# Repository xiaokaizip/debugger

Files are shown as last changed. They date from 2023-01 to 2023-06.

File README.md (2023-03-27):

#### 调试器电路

##### 主控（stm32f401rct6）

##### 屏幕（tft屏）

##### 闪存（W25Q32JVSSIQ）

##### 触摸功能（XPT2946）

##### 按键

#### 代码

##### tft屏驱动

- tft屏幕与主控使用spi通讯，然后为了提高屏幕的刷新率，我使用了DMA进行数据的传输。
- tft屏幕的配置更多还是使用网上的库，方便直接。
- 学会更好的使用DMA

##### 触摸功能

- 触摸的功能相对于tft屏幕的驱动来说，是比较好写，但是要完善也还不是很容易，它的功能还需再来研究。

==这两部分可以借鉴老朱的代码（手动狗头），养成写注释的习惯，等到功能写出来再来整理到readme中==

# Debegger

## 代码的设计

### tft屏幕显示

- spi的配置，如下图：（然后再开启个DMA就可以了）

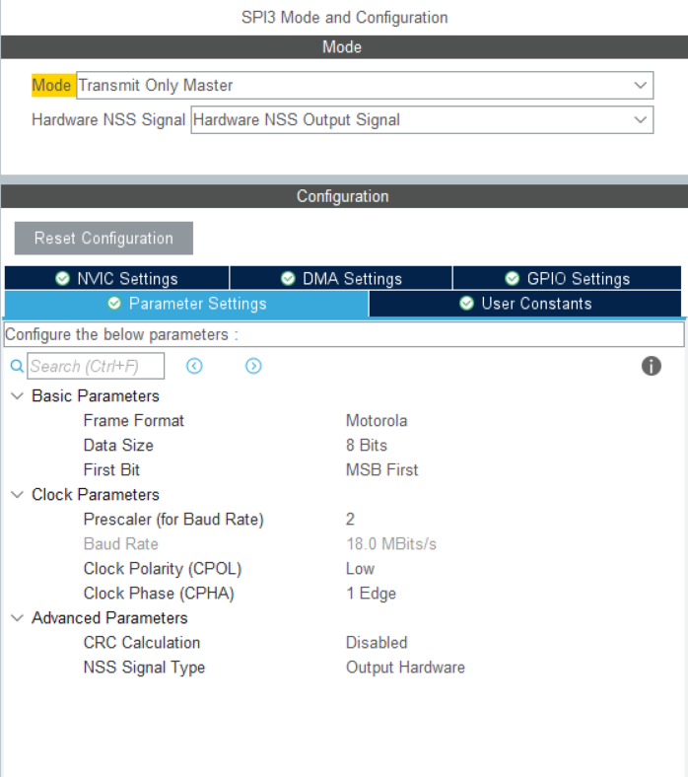
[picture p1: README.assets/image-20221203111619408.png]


- 屏幕的初始化还是使用普通的方法对其进行初始化（那些初始化的指令还没去了解）。

- 首先是屏幕的设计，目前的想法是，先将一整个屏幕的数据处理完，再使用DMA传输一次性完成传输。（已完成）

- 先将要处理的像素点存储到数组中

~~~c
volatile unsigned char lcd_buffer[128 * 160 * 2] = {0};

~~~

然后直接使用DMA将数据传输到ftf屏中

~~~c
    HAL_SPI_Transmit_DMA(&hspi3, (uint8_t *) lcd_buffer, 128 * 160 * 2);
~~~

- 然后就是对数组的处理了，每一个数组对应tft屏中的一个像素点，所以在处理时，只需将对应的像素点输入对应的颜色指令即可。
  - 在此代码中对应的字符大小为12*6，即宽为6像素，高为12像素。
  - 处理字符时，先从行开始处理的，依次向下处理。
  - 至于其他的方框，就是直接抄袭老朱的代码。（还需待我看懂）

### 串口数据的处理

##### 配置

- 首先是串口的接口，在本调试器中，使用的串口是USART1和UART4

  - usart1：typeC接口，具有usb2ttl芯片

    PA10->RX

    PA9->TX

  - uart4：使用的是gh1.25的接口。

    PC10->TX

    PC11->RX

- 发送数据的时候，还是用了轮询模式。接收数据的时候，使用的是中断模式。

##### 数据类型转换

- 串口传输的是8位的数，所以如果要传输更长的数据类型，需要转换一下数据的类型。在本例程中要传输的是float的数据，所以float和unsigned short 两种类型的数据相互转换。

- 将float转换为unsigned short

  ~~~c
  unsigned short FloatToInt16(float data0)
  ~~~

- 将unsigned short转换为float

  ~~~c
  float Int16ToFloat(unsigned short data0)
  
  ~~~

##### 传输格式

- 目前暂定传输和接收4个float类型数据（这四个数据分别为data1、data2、data3、data4）。使用长度为11的数据。

| 0 | 1 | 2 | 3 | 4 | 5 | 6 | 7 | 8 | 9 | 10 |
| ---- | ---- | ---- | ---- | ---- | ---- | ---- | ---- | ---- | --- | ---- |
| 0xff | 高位 | 低位 | 高位 | 低位 | 高位 | 低位 | 高位 | 低位 | 校准位 | 0xff |

- 第零位为起始位，指定为0xff，低十位为结束位，指定为0xff。
- 第1位是data1的高8位，第2位是data1低8位。其他的以此类推。
- 第9位是校准位，其实起这个名字可能不太合适，这一位的作用就是用来表示接收了多少个有效数据（非零数据）

## 图形界面的设计

### 现阶段流程图

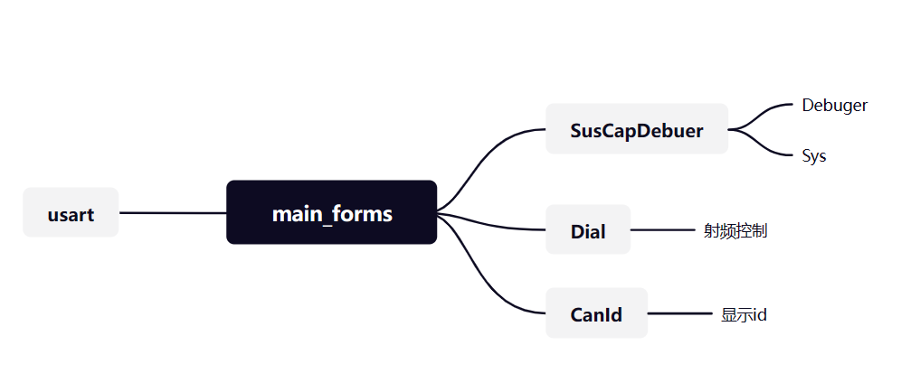
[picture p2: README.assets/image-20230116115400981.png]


- 在每一个界面中都有一个TurnBuck选项（除了main_forms界面），按下此界面就会回到上一个界面。这个回调的方法不知是要不要使用链表（有待思考）。

- 图形界面只是使用了按键（Button）以及标签（label）来设计的简易界面。Key1用来移动光标，Key2用来确定进入相依的界面，并使用回调函数还进行初始化，配合链表可能会有更好的效果。

### 设计思路

- key1为选择键，当key1按下时key_Select_flag++；同时相应的button将会高亮表示被选择到。
- 当按下key2时，为确定按键。此时key_Verify_flag=1。此时将会根据key_Select_flag的值调用 相应 的回调函数 进入相应的界面。然后key_Verify_flag被重新置零。
- 此流程是相对较简单的。后面的想法是使用链表来实现界面的切换 。

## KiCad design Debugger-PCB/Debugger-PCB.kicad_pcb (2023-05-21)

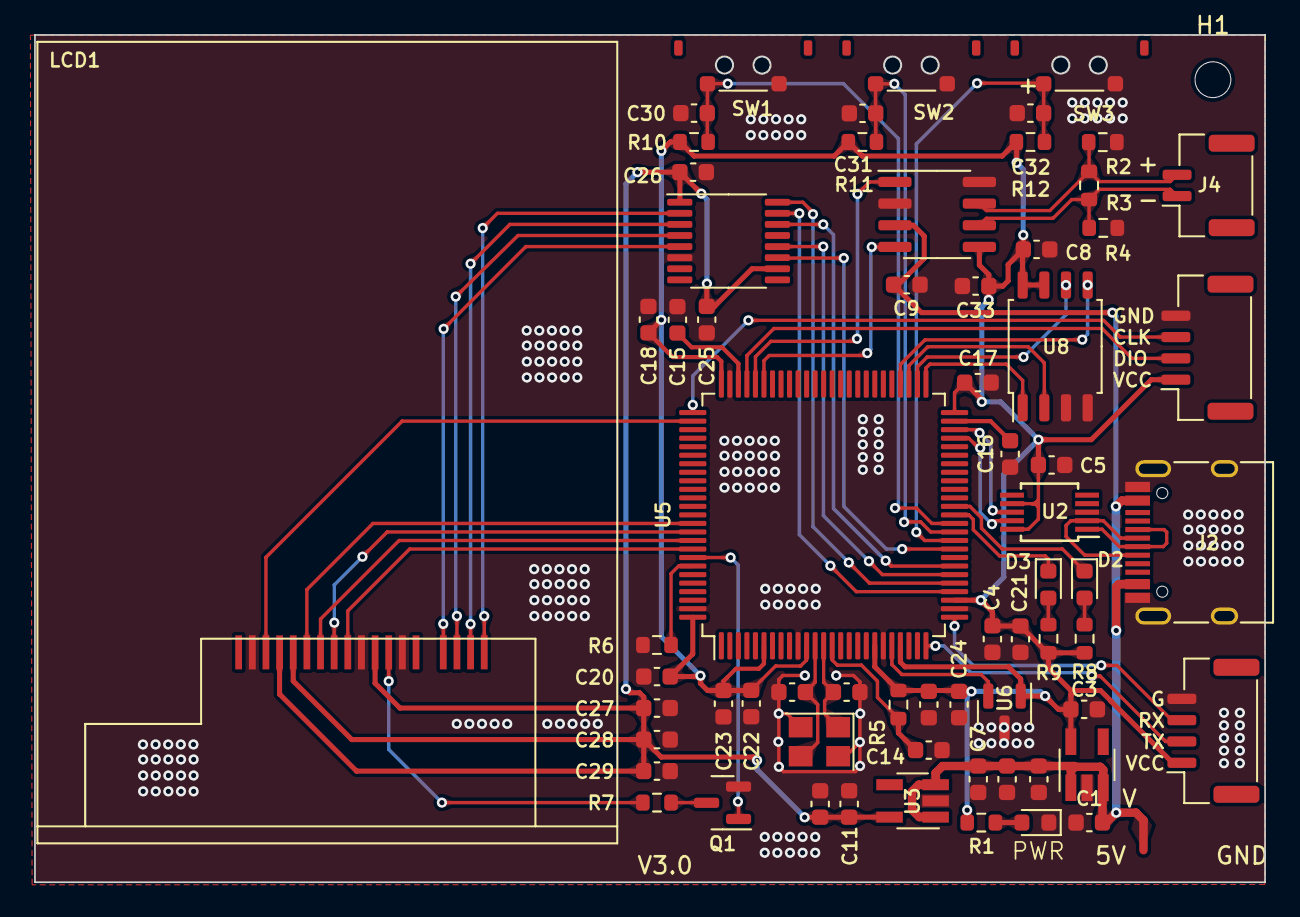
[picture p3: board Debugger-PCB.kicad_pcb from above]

Board: 2 copper layers, 72.1 x 49.7 mm, 67 parts (0 on the bottom side), 52 nets.

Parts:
C1, C4, C6, C11: 10u; C_0603_1608Metric
C2, C3, C5, C7, C8, C9, C10, C14, C17, C18, C19, C20, C21, C22, C23, C24, C25, C26, C27, C28, C29, C30, C31, C32, C33: 100n; C_0603_1608Metric
C12, C13: 12p; C_0603_1608Metric
C15, C16: 2.2u; C_0603_1608Metric
D1, D2, D3: LED; LED_0603_1608Metric
H1: mountinghole; MountingHole_2.1mm
J1, J3: Conn_01x04; JST_GH_SM04B-GHS-TB_1x04-1MP_P1.25mm_Horizontal
J2: USB_C_Receptacle_USB2.0; USB_C_Receptacle_HRO_TYPE-C-31-M-12
J4: Conn_01x02; JST_GH_SM02B-GHS-TB_1x02-1MP_P1.25mm_Horizontal
LCD1: 1.8inch-TFT-LCD; TFT-LCD1.8inch
Q1: S8050; SOT-23
R1, R8, R9, R10, R11, R12: 1k; R_0603_1608Metric
R2, R4, R5: 10k; R_0603_1608Metric
R3: 120; R_0603_1608Metric
R6: 10K; R_0603_1608Metric
R7: R; R_0603_1608Metric
SW1, SW2, SW3: SW_Push; button
U1, U3: HX9193; SOT-23-5_HandSoldering
U2: CH340E; MSOP-10_3x3mm_P0.5mm
U4: TJA1051T-3; SOIC-8_3.9x4.9mm_P1.27mm
U5: STM32F407VETx; LQFP-100_14x14mm_P0.5mm
U6: REF3030; SOT-23
U7: XPT2046TS; TSSOP-16_4.4x5mm_P0.65mm
U8: W25Q32JVSS; SOIC-8_5.23x5.23mm_P1.27mm
Y1: 12M; Crystal_SMD_3225-4Pin_3.2x2.5mm

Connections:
+5V: C1.1, C2.1, C6.1, C7.1, C9.1, J2.A4 (VBUS), J2.A9 (VBUS), J2.B4 (VBUS), J2.B9 (VBUS), U1.1 (VIN), U1.3 (EN), U3.1 (VIN), U3.3 (EN), U4.3 (VCC)
/Flash/SPI2_CS: U5.51 (PB12), U8.1 (~CS)
/Flash/SPI2_MISO: U5.53 (PB14), U8.2 (DO(IO1))
/Flash/SPI2_MOSI: U5.54 (PB15), U8.5 (DI(IO0))
/Flash/SPI2_SCK: U5.52 (PB13), U8.6 (CLK)
/Key&LED/KEY1: C30.1, R10.2, SW1.2, U5.37 (PB2)
/Key&LED/KEY2: C31.1, R11.2, SW2.2, U5.36 (PB1)
/Key&LED/KEY3: C32.1, R12.2, SW3.2, U5.35 (PB0)
/Key&LED/LED1: D2.1 (K), U5.39 (PE8)
/Key&LED/LED2: D3.1 (K), U5.38 (PE7)
/MCU/CAN_RX: U4.4 (RXD), U5.70 (PA11)
/MCU/CAN_TX: U4.1 (TXD), U5.71 (PA12)
/MCU/LCD_A0: LCD1.7 (A0), U5.90 (PB4)
/MCU/LCD_CLK: LCD1.9 (CLK), U5.89 (PB3)
/MCU/LCD_CS: LCD1.12 (CS), U5.77 (PA15)
/MCU/LCD_LED: Q1.1 (B), U5.93 (PB7)
/MCU/LCD_MOSI: LCD1.8 (DI), U5.91 (PB5)
/MCU/LCD_RST: LCD1.6 (~RESET), U5.92 (PB6)
/MCU/MCU_RXD: U2.8 (TXD), U5.48 (PB11)
/MCU/MCU_TXD: U2.9 (RXD), U5.47 (PB10)
/MCU/OSC_IN: C13.1, U5.12 (PH0), Y1.3
/MCU/OSC_OUT: C12.1, U5.13 (PH1), Y1.1
/MCU/RXD: J1.3, U5.26 (PA3)
/MCU/SWCLK: J3.3, U5.76 (PA14)
/MCU/SWDIO: J3.2, U5.72 (PA13)
/MCU/TOUCH_CLK: U5.30 (PA5), U7.16 (DCLK)
/MCU/TOUCH_CS: U5.29 (PA4), U7.15 (~CS)
/MCU/TOUCH_INT: U5.34 (PC5), U7.11 (~PENIRQ)
/MCU/TOUCH_MISO: U5.31 (PA6), U7.12 (DOUT)
/MCU/TOUCH_MOSI: U5.32 (PA7), U7.14 (DIN)
/MCU/TXD: J1.2, U5.25 (PA2)
/MCU/VREF: U5.21 (VREF+), U6.2 (OUT)
/Power&Port/CAN+: J4.2, R2.2, R3.1, U4.7 (CANH)
/Power&Port/CAN-: J4.1, R3.2, R4.1, U4.6 (CANL)
/Power&Port/DN: J2.A7 (D-), J2.B7 (D-), U2.2 (UD-)
/Power&Port/DP: J2.A6 (D+), J2.B6 (D+), U2.1 (UD+)
/TFT/LED-: LCD1.3 (LED-), R7.1
/TFT/T_XM: LCD1.16 (X-), U7.4 (XN)
/TFT/T_XP: LCD1.18 (X+), U7.2 (XP)
/TFT/T_YM: LCD1.15 (Y-), U7.5 (YN)
/TFT/T_YP: LCD1.17 (Y+), U7.3 (YP)
GND: C1.2, C2.2, C3.2, C4.2, C5.2, C6.2, C7.2, C8.2, C9.2, C10.2, C11.2, C12.2, C13.2, C14.1, C15.1, C16.1, C17.2, C18.2, C19.2, C20.2, C21.2, C22.2, C23.2, C24.2, C25.2, C26.2, C27.2, C28.2, C29.2, C30.2, C31.2, C32.2, C33.2, D1.1 (K), J1.4, J2.A1 (GND), J2.A12 (GND), J2.B1 (GND), J2.B12 (GND), J2.S1 (SHIELD), J3.4, LCD1.2 (GND), LCD1.5 (GND), LCD1.13 (GND), Q1.2 (E), R2.1, R4.2, R6.1, SW1.1, SW2.1, SW3.1, U1.2 (GND), U2.3 (GND), U3.2 (GND), U4.2 (GND), U4.8 (S), U5.10 (VSS), U5.20 (VSSA), U5.27 (VSS), U5.74 (VSS), U5.99 (VSS), U6.3 (GND), U7.6 (GND), U8.3 (IO2), U8.4 (GND), Y1.2, Y1.4
LCD_3V3: C10.1, C11.1, C25.1, C26.1, C27.1, C28.1, C29.1, LCD1.4 (LED+), LCD1.10 (VCC), LCD1.11 (IOVCC), U3.5 (VOUT), U7.1 (VCC), U7.10 (IOVDD)
unnamed: D1.2 (A), R1.2
unnamed: D2.2 (A), R8.2
unnamed: D3.2 (A), R9.2
unnamed: Q1.3 (C), R7.2
unnamed: R6.2, U5.94 (BOOT0)
unnamed: C14.2, R5.2, U5.14 (NRST)
unnamed: C16.2, U5.49 (VCAP_1)
unnamed: C15.2, U5.73 (VCAP_2)
VCC: C3.1, C4.1, C5.1, C8.1, C17.1, C18.1, C19.1, C20.1, C21.1, C22.1, C23.1, C24.1, C33.1, J1.1, J3.1, R1.1, R5.1, R8.1, R9.1, R10.1, R11.1, R12.1, U1.5 (VOUT), U2.7 (VCC), U2.10 (V3), U4.5 (VIO), U5.6 (VBAT), U5.11 (VDD), U5.19 (VDD), U5.22 (VDDA), U5.28 (VDD), U5.50 (VDD), U5.75 (VDD), U5.100 (VDD), U6.1 (IN), U8.7 (IO3), U8.8 (VCC)

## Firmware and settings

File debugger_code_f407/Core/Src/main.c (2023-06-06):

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
/* Includes ------------------------------------------------------------------*/
#include "main.h"
#include "cmsis_os.h"
#include "can.h"
#include "dma.h"
#include "spi.h"
#include "tim.h"
#include "usart.h"
#include "gpio.h"

/* USER CODE BEGIN Includes */
#include "lcd_init.h"
#include "key.h"
#include "motor.h"
#include "retarget.h"
#include "DynamicX.h"
#include "can_communication.h"
#include "BMI1088.h"
#include "test1.h"
#include "test2.h"
#include "test3.h"
#include "fifo.h"
/* USER CODE END Includes */

/* USER CODE BEGIN PTD */
uint8_t usart_data[8] = {0};

/* USER CODE END PTD */


void SystemClock_Config(void);

void MX_FREERTOS_Init(void);
/* USER CODE BEGIN PFP */
#define UART_TYPEC huart3
#define UART_GH huart2
/* USER CODE END PFP */

/* USER CODE BEGIN 0 */
///////////IMU////////////


extern IMU_measure_t IMU_measure;

unsigned short x = 0;
unsigned short y = 0;
uint8_t key_Select_flag = 0;
uint8_t key_Verify_flag = 0;
uint8_t key_Enter_flag = 0;

Forms_struct_t forms;
uint16_t usart_times = 0;
uint16_t can_times = 0;
uint16_t times = 0;
extern uint16_t can_id[6];
extern unsigned char lcd_buffer[130 * 162 * 2];

/*定时器中断*/





/* USER CODE END 0 */

/**
  * @brief  The application entry point.
  * @retval int
  */
int main(void) {
    /* MCU Configuration--------------------------------------------------------*/

    /* Reset of all peripherals, Initializes the Flash interface and the Systick. */
    HAL_Init();

    /* Configure the system clock */
    SystemClock_Config();

    /* Initialize all configured peripherals */
    MX_GPIO_Init();
    MX_DMA_Init();
    MX_CAN1_Init();
    MX_SPI1_Init();
    MX_SPI2_Init();
    MX_SPI3_Init();
    MX_USART2_UART_Init();
    MX_USART3_UART_Init();
    MX_TIM7_Init();
    /* USER CODE BEGIN 2 */
    HAL_GPIO_WritePin(GPIOB, GPIO_PIN_7, GPIO_PIN_SET);
    /* USER CODE END 2 */

    /* Call init function for freertos objects (in freertos.c) */
//    MX_FREERTOS_Init();
//
//    /* Start scheduler */
//    osKernelStart();
    /* We should never get here as control is now taken by the scheduler */
    /* Infinite loop */
    /* USER CODE BEGIN WHILE */
    RetargetInit(&huart3);//初始化打印的函数
    HAL_TIM_Base_Start_IT(&htim7);//开启定时器的中断

    can_init();//can初始化
    can_fifo_init();

    /*串口初中断初始化*/
    HAL_UART_Receive_IT(&huart2, usart_data, 8);
    HAL_UART_Receive_IT(&huart3, usart_data, 8);

    gui_config();//lcd屏幕初始化

    HAL_Delay(5);
    main_Form_Init();
    HAL_SPI_Transmit_DMA(&hspi3, (uint8_t *) lcd_buffer, 128 * 160 * 2);
    HAL_Delay(5);

    uint8_t delay_times = 10;
    int count = 0;

    //HAL_UART_Transmit(&huart3, "test=", 5, HAL_MAX_DELAY);




    while (1) {
        /* USER CODE END WHILE */

        /* USER CODE BEGIN 3 */

        while (1) {

            key_Enter_flag = Enter_Key();
//            if (xpt2046_readxy(&x, &y) != 0xFF) {
//
//                x = (unsigned short) ((float) x * (0.0363f) - 8.2952f);
//                y = (unsigned short) ((float) y * (0.0492f) - 8.5976f);
//                printf("%d,%d\n", x, y);
//                break;
//            }
            if (key_Enter_flag == 2) {
                key_Verify_flag = 1;
                HAL_GPIO_TogglePin(GPIOE, GPIO_PIN_7);
                break;
            }
            if (key_Enter_flag == 1) {
                key_Select_flag = (key_Select_flag + 1) % 5;
                HAL_GPIO_TogglePin(GPIOE, GPIO_PIN_8);

                break;
            }
            if (times > 10) {
                times = 0;
                break;
            }

        }
        // printf("key=%d\n", key_Enter_flag);
        while (1) {

            Form_UpdateEvent();
            HAL_Delay(5);

            HAL_SPI_Transmit_DMA(&hspi3, (uint8_t *) lcd_buffer, 128 * 160 * 2);
            HAL_Delay(10);

            if (times > 10) {
                times = 0;
                break;
            }
        }


    }
    /* USER CODE END 3 */
}

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
/**
  * @brief  Period elapsed callback in non blocking mode
  * @note   This function is called  when TIM6 interrupt took place, inside
  * HAL_TIM_IRQHandler(). It makes a direct call to HAL_IncTick() to increment
  * a global variable "uwTick" used as application time base.
  * @param  htim : TIM handle
  * @retval None
  */
void HAL_TIM_PeriodElapsedCallback(TIM_HandleTypeDef *htim) {
    if (htim->Instance == TIM6) {
        HAL_IncTick();
    }
    /* USER CODE BEGIN Callback 1 */
    usart_times++;
    times++;
    if (htim->Instance == TIM7) {
        get_IMU_attitude_algorithm_callback();
    }

    /* USER CODE END Callback 1 */
}

/**
  * @brief  This function is executed in case of error occurrence.
  * @retval None
  */
void Error_Handler(void) {
    /* USER CODE BEGIN Error_Handler_Debug */
    /* User can add his own implementation to report the HAL error return state */
    __disable_irq();
    while (1) {
    }
    /* USER CODE END Error_Handler_Debug */
}

#ifdef  USE_FULL_ASSERT
/**
  * @brief  Reports the name of the source file and the source line number
  *         where the assert_param error has occurred.
  * @param  file: pointer to the source file name
  * @param  line: assert_param error line source number
  * @retval None
  */
void assert_failed(uint8_t *file, uint32_t line)
{
  /* USER CODE BEGIN 6 */
  /* User can add his own implementation to report the file name and line number,
     ex: printf("Wrong parameters value: file %s on line %d\r\n", file, line) */
  /* USER CODE END 6 */
}
#endif /* USE_FULL_ASSERT */

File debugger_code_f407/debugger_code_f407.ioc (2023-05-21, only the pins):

Mcu.UserName=STM32F407VETx
PA11.GPIO_Label=CAN_RX
PA11.Signal=CAN1_RX
PA12.GPIO_Label=CAN_TX
PA12.Signal=CAN1_TX
PA13.Signal=SYS_JTMS-SWDIO
PA14.Signal=SYS_JTCK-SWCLK
PA15.GPIO_Label=LCD_CS
PA15.Signal=SPI3_NSS
PA2.GPIO_Label=TXD
PA2.Signal=USART2_TX
PA3.GPIO_Label=RXD
PA3.Signal=USART2_RX
PA4.GPIO_Label=TOUCH_CS
PA4.Signal=SPI1_NSS
PA5.GPIO_Label=TOUCH_CLK
PA5.Signal=SPI1_SCK
PA6.GPIO_Label=TOUCH_MISO
PA6.Signal=SPI1_MISO
PA7.GPIO_Label=TOUCH_MOSI
PA7.Signal=SPI1_MOSI
PB0.Signal=GPIO_Input
PB1.Signal=GPIO_Input
PB10.GPIO_Label=MCU_TXD
PB10.Signal=USART3_TX
PB11.GPIO_Label=MCU_RXD
PB11.Signal=USART3_RX
PB12.Signal=SPI2_NSS
PB13.Signal=SPI2_SCK
PB14.Signal=SPI2_MISO
PB15.Signal=SPI2_MOSI
PB2.Signal=GPIO_Input
PB3.GPIO_Label=LCD_CLK
PB3.Signal=SPI3_SCK
PB4.GPIO_Label=LCD_AO
PB4.Signal=GPIO_Output
PB5.GPIO_Label=LCD_MOSI
PB5.Signal=SPI3_MOSI
PB6.GPIO_Label=LCD_RST
PB6.Signal=GPIO_Output
PB7.GPIO_Label=LCD_LED
PB7.Signal=GPIO_Output
PC5.GPIO_Label=TOUCH_INT
PC5.Signal=GPIO_Output
PE7.GPIO_Label=LED1
PE7.Signal=GPIO_Output
PE8.GPIO_Label=LED2
PE8.Signal=GPIO_Output
PH0-OSC_IN.Signal=RCC_OSC_IN
PH1-OSC_OUT.Signal=RCC_OSC_OUT

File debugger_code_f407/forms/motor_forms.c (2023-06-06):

//
// Created by 86136 on 2023/3/27.
//

#include "motor_forms.h"
#include "main.h"
#include "fifo.h"
#include "can_data.h"

button_struct_t button_Turnbuck_Motor;
button_struct_t button_refresh_Motor;
extern unsigned char lcd_buffer[128 * 160 * 2];

extern unsigned short x;
extern unsigned short y;
extern uint8_t key_Select_flag;
extern uint8_t key_Enter_flag;
extern uint8_t key_Verify_flag;
extern Forms_struct_t forms;

extern uint16_t can_id[6];
extern uint16_t can_times;
extern fifo_s_t can_fifo_IMU;
can_data_t can_datas[6];

void Button_TurnBuck_CallBack_Motor(void *object) {

    main_Form_Init();
    forms.id = Main_Form;
    key_Select_flag = 0;

}

void Motor_Form_Init() {

    gui_clear_screan(C_WHITE);
    HAL_Delay(10);
    gui_button_init(&button_Turnbuck_Motor, 72, 138, 48, 18, "TurnBuck");
    gui_button_init(&button_refresh_Motor, 12, 138, 48, 18, "refresh");
    button_Turnbuck_Motor.callback = Button_TurnBuck_CallBack_Motor;
    gui_printf(12 * 4, 0, C_BLACK, C_WHITE, " id");
//    for (int i = 0; i < 6; i++) {
//        gui_draw_hline(0, 16 * (i + 1), 128, C_BLUE);
//        gui_printf(12 * 4, 16 * (i + 1) + 4, C_BLACK, C_WHITE, "0X%x", can_datas[i].id);
//    }
    gui_draw_hline(0, 16 * 7, 128, C_BLUE);

    gui_button_update(&button_Turnbuck_Motor, button_normal_status);
    gui_button_update(&button_refresh_Motor, button_click_status);
}

void Motor_Form_Load() {
    if (key_Select_flag >= 2) {
        key_Select_flag = 0;
    }
    switch (key_Select_flag) {
        case 0:
            gui_button_update(&button_refresh_Motor, button_click_status);
            gui_button_update(&button_Turnbuck_Motor, button_normal_status);
            key_Select_flag = 0;
            break;
        case 1:
            gui_button_update(&button_refresh_Motor, button_normal_status);
            gui_button_update(&button_Turnbuck_Motor, button_click_status);
            key_Select_flag = 1;
            break;
        default:
            key_Select_flag = 0;
            break;
    }

    if (can_times > 1000) {
        for (int i = 0; i < 6; i++) {
            can_id[i] = 0;
            can_times = 0;
        }
    }


    if (key_Select_flag == 0) {
        for (int i = 0; i < 6; i++) {
            gui_draw_hline(0, 16 * (i + 1), 128, C_BLUE);
            gui_printf(12 * 4, 16 * (i + 1) + 4, C_BLACK, C_WHITE, "     ");
            if (fifo_s_used(&can_fifo_IMU)) {
                fifo_s_gets(&can_fifo_IMU, (char *) &can_datas[i], 10);
                gui_printf(12 * 4, 16 * (i + 1) + 4, C_BLACK, C_WHITE, "0X%x", can_datas[i].id);
            } else {
                gui_printf(12 * 4, 16 * (i + 1) + 4, C_BLACK, C_WHITE, "0X%x", 0);

            }

        }
    }

    if (key_Verify_flag == 1) {
        if (key_Select_flag == 1) {
            button_Turnbuck_Motor.callback(&button_Turnbuck_Motor);
        }
        key_Verify_flag = 0;
    }
}

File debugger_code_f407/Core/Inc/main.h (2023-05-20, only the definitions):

#define TXD_Pin GPIO_PIN_2
#define TXD_GPIO_Port GPIOA
#define RXD_Pin GPIO_PIN_3
#define RXD_GPIO_Port GPIOA
#define TOUCH_CS_Pin GPIO_PIN_4
#define TOUCH_CS_GPIO_Port GPIOA
#define TOUCH_CLK_Pin GPIO_PIN_5
#define TOUCH_CLK_GPIO_Port GPIOA
#define TOUCH_MISO_Pin GPIO_PIN_6
#define TOUCH_MISO_GPIO_Port GPIOA
#define TOUCH_MOSI_Pin GPIO_PIN_7
#define TOUCH_MOSI_GPIO_Port GPIOA
#define TOUCH_INT_Pin GPIO_PIN_5
#define TOUCH_INT_GPIO_Port GPIOC
#define LED1_Pin GPIO_PIN_7
#define LED1_GPIO_Port GPIOE
#define LED2_Pin GPIO_PIN_8
#define LED2_GPIO_Port GPIOE
#define MCU_TXD_Pin GPIO_PIN_10
#define MCU_TXD_GPIO_Port GPIOB
#define MCU_RXD_Pin GPIO_PIN_11
#define MCU_RXD_GPIO_Port GPIOB
#define CAN_RX_Pin GPIO_PIN_11
#define CAN_RX_GPIO_Port GPIOA
#define CAN_TX_Pin GPIO_PIN_12
#define CAN_TX_GPIO_Port GPIOA
#define LCD_CS_Pin GPIO_PIN_15
#define LCD_CS_GPIO_Port GPIOA
#define LCD_CLK_Pin GPIO_PIN_3
#define LCD_CLK_GPIO_Port GPIOB
#define LCD_AO_Pin GPIO_PIN_4
#define LCD_AO_GPIO_Port GPIOB
#define LCD_MOSI_Pin GPIO_PIN_5
#define LCD_MOSI_GPIO_Port GPIOB
#define LCD_RST_Pin GPIO_PIN_6
#define LCD_RST_GPIO_Port GPIOB
#define LCD_LED_Pin GPIO_PIN_7
#define LCD_LED_GPIO_Port GPIOB

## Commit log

2022-11-11 the first commit of pcb and code
    [7735 serial.OBJ, Debugger-PCB.kicad_pcb, Debugger-PCB.kicad_sch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]
2022-11-12 fix some details of PCB
    [Debugger-PCB-B_Cu.gbr, Debugger-PCB-B_Mask.gbr, Debugger-PCB-B_Paste.gbr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]
2022-12-07 add gui、forms、devices.Add finsh the forms of main,suscapDebuger ……
2023-01-01 Finish the GUI
    [Debugger-PCB-B_Cu.gbr, Debugger-PCB-B_Mask.gbr, Debugger-PCB-B_Paste.gbr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]
2023-01-15 Charge the file structure of project.(Actually,it has been charged from last commit.This commit has improved the project.)
    [board.cfg, stm32f1x.cfg]
2023-03-27 Charge the CAN communication file. Add the motor_forms.c and motor_forms.h to see the motor CAN's id. Add the imu_forms.c and imu_forms.h to see the imu id and datas.
2023-03-27 Add the motor_forms.c and motor_forms.h . Add the imu_forms.c and imu_forms.h
2023-04-04 Added data fusion for IMUs
2023-04-30 change the file name debugger-code into debugger_code_f103. Change the stm32f103rct6 into stm32f407vet6. Add file debugger_code_f407
    [Debugger-PCB-B_Cu.gbr, Debugger-PCB-B_Mask.gbr, Debugger-PCB-B_Paste.gbr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]
2023-05-20 Finish the config of stm32f407vet6 with debugger board.
    [board.cfg]
2023-05-21 Add FreeRtos. Add fifo file from C board into support file folder. Using fifo to receive can datas. Creating data_processing file folder to sort the file of processing data. (All the changes are in d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
    [Debugger-PCB-B_Cu.gbr, Debugger-PCB-B_Mask.gbr, Debugger-PCB-B_Paste.gbr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]
2023-06-06 Try to use fifo to receive the datas of IMU, but fail. Using the forms.c of MM32 which is creating by LaoZhu.
    [BMI1088.h, can_communication.c, can_data.c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]

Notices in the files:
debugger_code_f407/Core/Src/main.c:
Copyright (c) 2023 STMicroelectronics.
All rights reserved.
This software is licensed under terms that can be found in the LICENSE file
